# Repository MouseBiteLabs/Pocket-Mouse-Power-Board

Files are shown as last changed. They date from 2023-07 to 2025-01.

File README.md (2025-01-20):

# Pocket Mouse Power Board

This is a power regulator board for my <a href="https://github.com/MouseBiteLabs/Game-Boy-Pocket-Color">Game Boy Pocket Color (MGBC)</a> project. This *should* work perfectly fine on a regular Game Boy Color or Pocket, but I haven't exhaustively tested it yet. I have, however, tested it in my MGBC project extensively.

Please note I developed this board for use with the MGBC with NiMH AAA batteries. If you use this power board on the MGBC, your experience with alkaline AAAs may vary. See the section below the BOM for information on improving the experience with alkaline batteries.

etsygreen



*Note: Image of assembled board shows v1.2, rather than the current v1.3. The differences are minimal - see details below.*

## Disclaimer

I highly suggest testing this board before installation in a Game Boy. Failure to do so may result in an irreversibly damaged Game Boy. See the testing sequence below.

**This is a complicated build that requires high level soldering skills. Please do not attempt if you do not have advanced soldering experience. Do not attempt to hand-solder the QFN component on this board, you must use either hot air or a hot plate. I am not responsible for any damage done to you or your Game Boy. You accept any and all risks associated with attempting this project.**

## Board Characteristics and Order Information

The zipped folder contains all the gerber files for this board.
-	Layers: 2
-	Thickness: 1.6mm or thinner
-	Surface Finish: ENIG or HASL (ENIG may be easier to solder)

**I sell this board on Etsy, so you don't have to buy multiples from board fabricators:**

<a href="https://mousebitelabs.etsy.com/listing/1473483915/pocket-mouse-power-board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">PCB from Etsy</a> 

You can alternatively use the zipped folder at any board fabricator you like. You may also buy the board from PCBWay using this link (disclosure: I receive 10% of the sale value to go towards future PCB orders):

<a href="https://www.pcbway.com/project/shareproject/Pocket_Mouse_Power_Board_3c1c3bc6.html">PCB from PCBWay</a> 

And finally, insideGadgets sells these boards fully populated!



## Features

Some features of this power board include: 

* Changing the power switch to a "soft power switch," meaning the main power of the Game Boy does not flow through the switch. A dirty power switch can severly impact performance, so using this scheme can remedy that issue.
* Generally improved efficiency over the OEM regulator, and increased switching frequency.
* Bootloop protection circuitry to prevent overdischarge of AAA batteries, and to allow the Game Boy to die gracefully instead of violently stuttering until the regulator gives up.

I generally recommend using rechargeable NiMH batteries with this board, over alkaline batteries. <a href="https://www.amazon.com/Panasonic-BK-4HCCA8BA-eneloop-Pre-Charged-Rechargeable/dp/B00JHKSL0A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">Here's a listing for the eneloop pro batteries I use in all of my Game Boys.</a> Other brands of rechargeable batteries I have seen used are Ikea LADDA batteries, and Jugee batteries.

## Testing

I suggest testing the assembled board externally before mounting it to your Game Boy. If you have misassembled it, a part is incorrect, if there is a hidden solder bridge, or one of many other issues - your 5 V supply might be too high when you turn it on! This is not ideal for your Game Boy! So, please, test the board before you fully connect it to the system.



### Version 1.3 Testing
- Connect pin 3 (white box) to negative side of the input voltage source - such as a battery holder with alligator clips or a benchtop power supply.
- Connect pins 1 and 2 (red and yellow boxes) to positive side of the input voltage source. The voltage from the power source must be at least 2.2 V (do not exceed ~4.5 V).
- Turn power on.
- Measure voltage using a multimeter in DC voltage mode - positive probe on pin 7 (blue box) and negative probe on pin 3 (white box). The voltage should read between 4.95 V and 5.05 V.

If your board does not turn on, check orientation of D1 (and other components).



### Version 1.2 Testing
- Connect pin 3 (white box) to negative side of the input voltage source - such as a battery holder with alligator clips or a benchtop power supply.
- Connect pin 2 (yellow box) to positive side of the input voltage source. The voltage from the power source must be at least 2.2 V (do not exceed ~4.5 V).
- Turn power on. Wait 10 seconds for capacitors to fully charge.
- Connect pin 1 (red box) to pin 2 (yellow box) using a switch (preferred) or some other means, such as a wire.
- Measure voltage using a multimeter in DC voltage mode - positive probe on pin 7 (blue box) and negative probe on pin 3 (white box). The voltage should read between 4.95 V and 5.05 V.

### Safely Testing Any Version Using a Game Boy
- Connect pins 1 (red box), 2 (yellow box), and 3 (white box) to the proper locations on the Game Boy circuit board using wire. DO NOT CONNECT PIN 7 (blue box)!!
- Connect input voltage source to the battery tabs (battery holder with alligator clips, power supply, or simply putting the board in the back half of a Game Boy shell with batteries). Voltage source must be at least 2.2 V (do not exceed ~4.5 V).
- Turn the power switch on.
- Measure voltage using a multimeter in DC voltage mode - positive probe on pin 7 (blue box) and negative probe on pin 3 (white box). The voltage should read between 4.95 V and 5.05 V.

## Using with a Game Boy Color or Game Boy Pocket

*Note: This board only supplies the 5V power rail - there are no LCD supplies. This board is only a proper replacement if you have modded your system with a modern IPS kit.*

If you wish to use this on an original Game Boy system, you must:

* Remove U5 from the Game Boy circuit board (the DC/DC converter board) and replace it with this one. Make sure you have a header pin populated for pin 2 on the socket!
* On the main Game Boy PCB, add a wire from pin 2 of the U5 socket to the node labelled SW1-VCC. This node connects to the power switch and F1, so you can choose either points. Note that Game Boy Pockets do not have pin 2 available, so you must run a wire directly from the Pocket Mouse Power Board's pin 2 instead.
* If you are soldering a wire to the fuse directly, **MAKE SURE YOU CHOOSE THE CORRECT SIDE**. It must be the side that's directly connected to the power switch. A multimeter will not tell you which side of the fuse is which if you have the fuse on the board.



## Bill of Materials

A prepopulated cart from Mouser can be found here: https://www.mouser.com/ProjectManager/ProjectDetail.aspx?AccessID=9fcbf0306d. The quantities in the cart are enough such that there is at least one extra component in case you drop or lose one, except for U1 and U2 as they are more expensive. You may want to consider ordering multiple quantities of those parts just in case.

If parts are out of stock or backordered, you can search for the parts on Digikey. The only parts that have no replacements are U1 and U2, every other component has suitable alternate parts you can search for. 

(Is C1 and C3 out of stock? Try GRM21BR61A476ME15K.)

C2 is removed on v1.3, and D1 is only used on v1.3.

| Reference Designators | Qty | Value/Part Number  | Package | Description | Comment | Source |
| --- | --- | --- | --- | --- | --- | --- |
| C1, C3 | 2 | 47uF | 0805 | Capacitor (MLCC) | X5R or better, 10V or higher | [https://www.mouser.com/ProductDetail/Murata-Electronics/GRM21BR61A476ME15L?qs=hNud%2FORuBR2%2FEB7WUpdltg%3D%3D](https://www.mouser.com/ProductDetail/Murata-Electronics/GRM21BR61A476ME15L?qs=hNud%2FORuBR2%2FEB7WUpdltg%3D%3D) |
| C4 | 1 | 0.1uF | 0603 | Capacitor (MLCC) | C2 is removed on v1.3 | [https://www.mouser.com/ProductDetail/KEMET/C0603C104M3RACTU?qs=7q2aiX3Gdlh4qBRaMcnohQ%3D%3D](https://www.mouser.com/ProductDetail/KEMET/C0603C104M3RACTU?qs=7q2aiX3Gdlh4qBRaMcnohQ%3D%3D) |
| C5 | 1 | 22uF | 0805 | Capacitor (MLCC) | X5R or better, 16V or higher | [https://www.mouser.com/ProductDetail/Murata-Electronics/GRM21BR61E226ME44K?qs=hNud%2FORuBR25jDsUehWlrQ%3D%3D](https://www.mouser.com/ProductDetail/Murata-Electronics/GRM21BR61E226ME44K?qs=hNud%2FORuBR25jDsUehWlrQ%3D%3D) |
| D1 | 1 | BAT42 | SOD323  | Schottky Diode | Only used on v1.3 | https://www.mouser.com/ProductDetail/78-BAT42WS-E3-18 |
| L1 | 1 | 2.2uH | 1212 | Inductor | Saturation current higher than 1 A preferred | https://www.mouser.com/ProductDetail/810-VLS3012HBX2R2M-N |
| Q1 | 1 | MMBT3906 | SOT23 | PNP BJT | | [https://www.mouser.com/ProductDetail/Micro-Commercial-Components-MCC/MMBT3906HE3-TP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](https://www.mouser.com/ProductDetail/Micro-Commercial-Components-MCC/MMBT3906HE3-TP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) |
| Q2, Q4 | 2 | 2N7002 | SOT23 | N-channel MOSFET | | [https://www.mouser.com/ProductDetail/Nexperia/2N7002NXBKR?qs=%252B6g0mu59x7J2ddJstTJGkQ%3D%3D](https://www.mouser.com/ProductDetail/Nexperia/2N7002NXBKR?qs=%252B6g0mu59x7J2ddJstTJGkQ%3D%3D) |
| Q3 | 1 | MMBT3904 | SOT23 | NPN BJT | | [https://www.mouser.com/ProductDetail/Nexperia/MMBT3904VL?qs=cnAQGvEIVkKbCwIpHJoHxQ%3D%3D](https://www.mouser.com/ProductDetail/Nexperia/MMBT3904VL?qs=cnAQGvEIVkKbCwIpHJoHxQ%3D%3D) |
| R1, R4, R8 | 3 | 100k | 0603 | Resistor | | [https://www.mouser.com/ProductDetail/YAGEO/RC0603FR-07100KL?qs=e1ok2LiJcmaihem8Va5%2Fsw%3D%3D](https://www.mouser.com/ProductDetail/YAGEO/RC0603FR-07100KL?qs=e1ok2LiJcmaihem8Va5%2Fsw%3D%3D) |
| R2, R3, R5 | 3 | 10k | 0603 | Resistor | | [https://www.mouser.com/ProductDetail/YAGEO/RC0603FR-0710KL?qs=grNVn54RoB%252B3GtjbJj3wJQ%3D%3D](https://www.mouser.com/ProductDetail/YAGEO/RC0603FR-0710KL?qs=grNVn54RoB%252B3GtjbJj3wJQ%3D%3D) |
| R6 | 1 | 47k | 0603 | Resistor | | [https://www.mouser.com/ProductDetail/YAGEO/RC0603FR-0747KL?qs=gt6vzsuosg3jXzmCiDCCdg%3D%3D](https://www.mouser.com/ProductDetail/YAGEO/RC0603FR-0747KL?qs=gt6vzsuosg3jXzmCiDCCdg%3D%3D) |
| U1 | 1 | TPS61202 | VSON-10 | Boost Converter  | | [https://www.mouser.com/ProductDetail/Texas-Instruments/TPS61202DRCR?qs=KS%252B%252BetD%2FUt9ba9GgZBolfg%3D%3D](https://www.mouser.com/ProductDetail/Texas-Instruments/TPS61202DRCR?qs=KS%252B%252BetD%2FUt9ba9GgZBolfg%3D%3D) |
| U2 | 1 | TPS3840DL20 | SOT23-5 | Supervisory IC | | [https://www.mouser.com/ProductDetail/Texas-Instruments/TPS3840DL20DBVR?qs=T3oQrply3y%2FZsfSrLIG7Ww%3D%3D](https://www.mouser.com/ProductDetail/Texas-Instruments/TPS3840DL20DBVR?qs=T3oQrply3y%2FZsfSrLIG7Ww%3D%3D) |
| -- | 1 | 10129378-904001BLF | -- | 1x4 Header Pins  | | [https://www.mouser.com/ProductDetail/649-1012937890401BLF](https://www.mouser.com/ProductDetail/649-1012937890401BLF) |
| -- | 1 | 10129378-903001BLF | -- | 1x3 Header Pins  | | [https://www.mouser.com/ProductDetail/649-1012937890301BLF](https://www.mouser.com/ProductDetail/649-1012937890301BLF) |

## Minimized Parts List and/or for use with Alkaline AAAs

If you don't want the undervoltage lockout mechanism, which may be specifically desirable with alkaline AAAs, you can assemble the board without the following components:
- Capacitor: C1
- Diode: D1
- Resistors: R1, R2, R3, R4, R6
- Transistors: Q1, Q2, Q3, Q4
- IC: U2

If you have built the system, but find alkaline batteries don't last as long as you would expect, you can simply remove U2 and keep everything else on the board to achieve the same effect.

## Potential Issues

- If you use AAA alkaline batteries (for Game Boy Pocket or Pocket Color), you may find that after using them for a few hours (or if you use mismatched batteries), the Game Boy might stutter a bit when turning the power switch on, taking a few seconds to fully turn on. This is likely due to a higher internal resistance of alkaline batteries as they've been discharged, compared to rechargeable NiMH batteries. I generally recommend using rechargeable NiMH AAA batteries over alkalines to avoid this issue. If you are a huge fan of alkaline batteries, you can remove U2 to "extend" the life of the system and prevent the struggling start-up on alkaline batteries.
- Using a flash cart, such as the Everdrive or EZ-Flash, the power draw during start-up may be too high and cause the battery voltage to drop below the 2V threshold. You may be able to get it to boot by turning the power switch off and on again. Regardless, this should only occur when you have very low battery life. The components I have chosen should effectively prevent this error from occurring, but I have not tested every system configuration possible.
- **Version 1.2 only:** When first placing batteries in, you must wait a few seconds for the capacitors to charge up, before it will operate correctly. This is only upon first insertion - once the batteries have been in the system for longer than a few seconds, it will operate completely normally.

## Revision History

### v1.3
- Added diode to fast charge C1 (removes need to wait a few seconds before use after placing batteries in the first time)
- Added test points for various nets
- Removed C2

### v1.2
- Changed C1 to 0805 size
- Added test points for U2 supply voltage and PSU_EN net

### v1.1
- Removed some unnecessary components
- Changed the voltage cut-off to 2V instead of 1.8V to enable reliable bootloop prevention

### v1.0
- Release version

## License
<br />This work is licensed under a <a rel="license" href="http://creativecommons.org/licenses/by-sa/4.0/">Creative Commons Attribution-ShareAlike 4.0 International License</a>. You are able to copy and redistribute the material in any medium or format, as well as remix, transform, or build upon the material for any purpose (even commercial) - but you **must** give appropriate credit, provide a link to the license, and indicate if any changes were made.

©MouseBiteLabs 2023

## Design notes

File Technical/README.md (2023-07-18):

# Technical Design Document

This write-up serves as a technical explainer as to how the Pocket Mouse Power (PMP) Board operates. The board takes the shape of the original Game Boy Color (CGB) power board, and should also serve as a Game Boy Pocket (MGB) replacement. As mentioned in the main file, the board only supplies 5 V output - therefore, original LCD screens are unsupported. You must have a modded Game Boy with an IPS kit in order to use this board properly, as many of those do not require the use of the LCD supplies. (Some MGB screen kits utilize the -18 V supply, though, so your mileage may vary)

## Schematic and Board Interfacing

The Pocket Mouse has seven pins, similar to the Game Boy Color power board. In the below schematic, the pins are laid out similar to how they appear on the board - three on the left, four on the right. Some of these pins serve slightly different functions, so I will compare them here:

- Pin 1 is the input voltage (from the batteries or DC jack, labelled "SW" in the schematic) *after* the power switch - when the switch is off, pin 1 sees no voltage. This retains the same function as the original power board for the CGB and MGB.
- Pin 2 is permanently connected to VCC, which is the input voltage *before* the power switch. This differs from the CGB and MGB, where this pin was not connected to anything (or completely missing).
- Pin 3 is GND, same as CGB and MGB.
- Pin 4 is also GND, same as the CGB. This pin did not appear on the MGB power board.
- Pin 5 is not used. This was the 13.6 V rail for the positive supply on the LCD screen of the CGB. This was GND on the MGB (and was called pin 4).
- Pin 6 is also not used. On a CGB, this pin is supposed to be the -15 V rail for the negative LCD supply. This was -18 V (VEE) for the MGB's LCD screen (and called pin 5).
- Pin 7 is the 5 V output, same as CGB and MGB.

Here's the schematic in full:

schematic

## Boost Converter (U1)

Like many other aftermarket reuglator boards for Game Boys, the PMP uses the TPS61202 boost converter. <a href="https://www.ti.com/lit/ds/symlink/tps61202.pdf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">The datasheet for this chip</a> provides many sample circuit layouts, all of which are considerably simple to follow as the chip takes care of most of the complicated aspects, leaving the user to only need to pick a handful of discrete parts. In my case, this pretty much means just the input and output capacitors (C3 and C5, respectively) and the boost inductor L1; the aux capacitor, C4, is simply assigned at 0.1 uF. 

The boost converter is enabled when the voltage on the EN pin is above 400 mV. The voltage divider made by R5 and R8 (supplied by the output of the power switch) means the voltage is ~91% of the input voltage to the system if the switch is on, or zero if the switch is off or the undervoltage lockout is latched by U2. The undervoltage lockout is explained in the next subheadings.

The boost inductor L1 is recommended to be at minimum Vin * 0.5 (us/A), but more generally just 2.2 uH as a "best performance" value. Inductance loss due to saturation should be taken into account - the maximum current the power board should output is less than 250 mA, but the inductor I chose saturates at ~1.2 A, which should be plenty of headroom.

The output capacitor is recommended to be at least five times the value of L1 (in uH), so in this case, greater than ~11 uF. There is no upper limit to the output capacitance. 22 uF seems like a good fit. The input capacitor should be large enough to supply the boost converter with enough power during transients. Any value above 4.7 uF is recommended. Since I'm already using a 22 uF for the output, might as well use that for the input as well.

Ceramic capacitors experience a drop in capacitance as the DC voltage bias across them increases, so it's always good to have headroom. X5R or X7R capacitors are recommended due to their temperature stability. The graph below is an example of the drop in capacitance ceramic capacitors can experience with respect to the applied voltage across them. Therefore, the input and output capacitors I have chosen are at least 5x their rated value to keep capacitance losses below 20%.



<i>Source: <a href="https://www.omicron-lab.com/fileadmin/assets/Bode_100/ApplicationNotes/DC_Biased/App_Note_DC_Bias_Impedance_Caps_V2_0.pdf">DC Biased Impedance Measurements Capacitors</a></i>

## Undervoltage Detection (U2)

U2 is a TPS3840 chip which monitors the voltage on the batteries via the VDD pin. When it detects the voltage has gone below a specific threshold, the /RESET pin is pulled low. This output is open-drain, so it does not affect the PSU_EN net while not in an error state. The ultimate effect of this chip is it will disable the boost converter if the battery voltage drops too low; this is to 1) protect the batteries from overdischarging and 2) to prevent extremely annoying bootloops when the batteries die.

The specific part I chose was the TPS3840DL20. The DL indicates the /RESET is an active-low open-drain output. (PL would indicate active-low push-pull output, PH would indicate active-high push-pull, both of which aren’t suitable for my specific application). The threshold voltage is determined by the last two numbers, which for my selection is 20 for 2.0 V. I chose this cutoff point of 2 V because the voltage level is still high enough to reliably activate the transistor circuit for the latching circuit (explained in the next subheading). I found that using a threshold at 1.8 V instead caused unreliable operation, because the batteries are too drained when they reach that level. The added time for dropping the cutoff down 200 mV was only about 5 minutes of gameplay, so it's a worthy sacrifice to bump it up to 2 V instead.

You may notice the VDD pin of U2 isn’t directly powered by the battery voltage (VCC). C1 and R6 on the battery voltage filter out any power supply transients, which can be seen during normal gameplay, but also during initial turn-on. During the boost converter start-up, the loads on the 5 V supply will draw a considerable amount of current from the batteries for nearly a full second, causing the battery voltage to dip quite low - low enough that U2 would detect an undervoltage and shut off the converter before it could finish starting up! Furthermore, loud audio can introduce kHz range ripple on the battery voltage, so the low pass filter will smooth that out to prevent nuisance faults. The current draw of the TPS3840 is less than a microamp, so the voltage drop across R6 is negligible for detecting the *actual* dead battery case. The low consumption also means U2 won't have any perceptible impact to battery life despite always being connected to the batteries.

D1 is included to quickly charge up C1 when batteries are first inserted into the system. It does not appreciably contribute to the discharge of C1.

The CT pin on this chip introduces a delayed start function. Adding a 0.1 uF capacitor to this pin will cause the /RESET output to be held low for approximately 62 milliseconds no matter what the supply voltage is. This isn't necessary for this implementation, so it goes unused.

## Latching Circuit (Q1 - Q4)

Without a latching circuit, when U1's enable pin is pulled low by U2 to disable the output once the batteries are discharged enough, all loads will turn off. This has the effect of removing the load of the Game Boy from the batteries. When a load is disconnected from a battery, the voltage rises to a higher value (no load voltage, or open circuit voltage). Because the battery voltage is now once again higher than the undervoltage threshold of U2, the EN pin on U1 is released, and the boost converter restarts. But... that then increases the load on the batteries, the battery voltage drops below U2's detection threshold, and the system shuts off again. And that cycle would repeat. A bootloop! The end effect is a stuttering system with flashing power LED and screen, and a whine or tapping sound out of the speaker. Not the graceful death the original Game Boy experienced when the batteries ran out of juice. 

In order to fix this, a latching circuit is implemented alongisde U2, so that as soon as the batteries die the first time, the system keeps itself shut off until the power switch was cycled off and on again to reset the latch. The latching circuit consists of Q1 through Q4 and R1 through R4. <a href="https://www.ti.com/lit/an/snva836a/snva836a.pdf">This appnote from TI explains the process.</a>

A short explanation: turning on Q2 with a sufficient gate-source voltage sets up the latch. The next time the gate of Q2 (the PSU_EN net) is pulled to GND by the /RESET pin, Q4 is turned on to conduct and the /MR pin (master reset) is also pulled low. On the TPS3840, whenever /MR is low, /RESET will also automatically be pulled low no matter if VCC is above or below the undervoltage trip point. So even if the voltage rises back up above the trip limit, /RESET will keep Q4 conducting, which keeps /MR low as well. So the only way to reset the whole thing is to turn the power switch off and reset the latch.

An added bonus is that there's an internal 100k pull-up resistor on /MR to the VDD pin. When /MR is latched to GND, this causes a voltage divider to be set up with this pull-up resistor and R6, which is also 100k. This cuts the battery voltage that U2 sees in half, and ensures the voltage on the VDD pin is below the "VDD(min)" limit for operation (1.5V), further keeping the enable line from powering on the boost converter.

## Resources
-	<a href="https://www.ti.com/lit/ds/symlink/tps61202.pdf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">TPS61202 datasheet</a>
-	<a href="https://www.ti.com/lit/ds/symlink/tps3840.pdf?ts=1656386735143">TPS3840 datasheet</a>
-	<a href="https://www.ti.com/lit/an/snva836a/snva836a.pdf">Latching a Voltage Supervisor Application Note</a>
- <a href="https://www.omicron-lab.com/fileadmin/assets/Bode_100/ApplicationNotes/DC_Biased/App_Note_DC_Bias_Impedance_Caps_V2_0.pdf">DC Biased Impedance Measurements Capacitors</a></i>

## License
<br />This work is licensed under a <a rel="license" href="http://creativecommons.org/licenses/by-sa/4.0/">Creative Commons Attribution-ShareAlike 4.0 International License</a>. You are able to copy and redistribute the material in any medium or format, as well as remix, transform, or build upon the material for any purpose (even commercial) - but you **must** give appropriate credit, provide a link to the license, and indicate if any changes were made.

©MouseBiteLabs 2023

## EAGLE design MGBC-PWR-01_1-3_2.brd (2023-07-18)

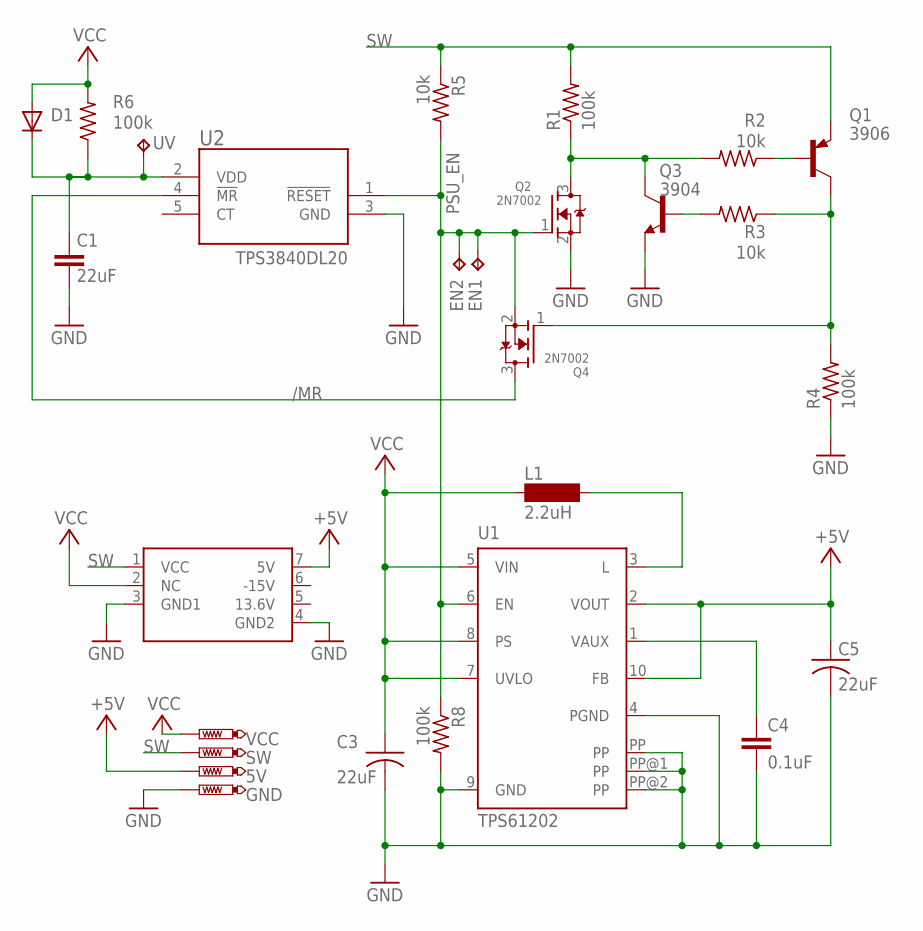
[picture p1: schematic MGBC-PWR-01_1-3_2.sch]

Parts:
5V: PTR1B1,27; B1,27
C1, C3, C5: 22uF; C0805
C4: 0.1uF; C0603
D1: DIODESOD-323F; SOD-323F
EN1: TPTP09R; TP09R
EN2: TPB1,27; B1,27
GND: PTR1B1,27; B1,27
L1: 2.2uH; 1212
Q1: MMBT3906LT1SMD; SOT23-BEC
Q2, Q4: 2N7002; SOT23
Q3: 3904; SOT23-BEC
R1, R4, R6, R8: 100k; R0603
R2, R3, R5: 10k; R0603
SW: PTR1B1,27; B1,27
U1: TPS61202; S-PDSO-N10
U2: TPS3840; SOT-23-5
U$1: MGB-PWR_BD; MGB-PWRBD
UV: TPB1,27; B1,27
VCC: PTR1B1,27; B1,27

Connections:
13.6V: U$1.5 (13.6V)
+5V: 5V.TP, C5.1, U1.2 (VOUT), U1.10 (FB), U$1.7 (5V)
-15V: U$1.6 (-15V)
/MR: Q4.3 (D), U2.4 (!MR)
GND: C1.2, C3.2, C4.2, C5.2, GND.TP, Q2.2 (S), Q3.E, R4.1, R8.2, U1.4 (PGND), U1.9 (GND), U1.PP, U1.PP@1 (PP), U1.PP@2 (PP), U2.3 (GND), U$1.3 (GND1), U$1.4 (GND2)
unnamed: C1.1, D1.C, R6.1, U2.2 (VDD), UV.TP
unnamed: Q1.B, R2.1
unnamed: Q1.C, Q4.1 (G), R3.1, R4.2
unnamed: Q3.B, R3.2
unnamed: Q2.3 (D), Q3.C, R1.1, R2.2
unnamed: L1.2, U1.3 (L)
unnamed: C4.1, U1.1 (VAUX)
PSU_EN: EN1.TP, EN2.TP, Q2.1 (G), Q4.2 (S), R5.2, R8.1, U1.6 (EN), U2.1 (!RESET)
SW: Q1.E, R1.2, R5.1, SW.TP, U$1.1 (VCC)
VCC: C3.1, D1.A, L1.1, R6.2, U1.5 (VIN), U1.7 (UVLO), U1.8 (PS), U$1.2 (NC), VCC.TP

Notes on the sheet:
3906
TPS3840DL20

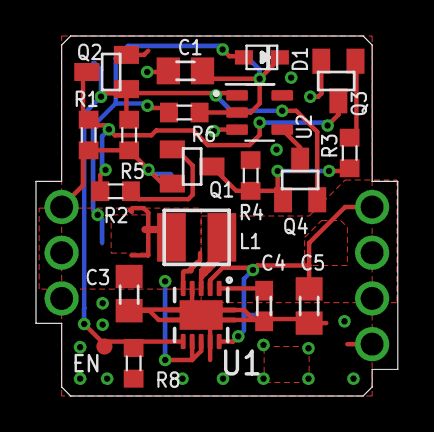
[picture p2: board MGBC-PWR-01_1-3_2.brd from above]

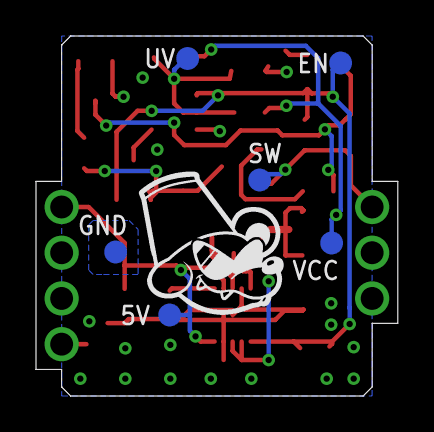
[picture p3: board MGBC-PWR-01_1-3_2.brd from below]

Board: 2 copper layers, 20.1 x 20.0 mm, 27 parts (6 on the bottom side), 13 nets.

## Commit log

2023-04-03 Update BOM
2023-04-03 Update BOM and disclaimer
2023-04-03 Update BOM quantities
2023-04-04 Upload board and schematic files
    [MGBC-PWR-01_1-1.brd, MGBC-PWR-01_1-1.sch]
2023-04-04 Upload gerbers
